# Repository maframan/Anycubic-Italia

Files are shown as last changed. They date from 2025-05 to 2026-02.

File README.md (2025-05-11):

# Anycubic-Italia
Repository ufficiale del gruppo telegram https://t.me/mfAnycubicIT

All'interno di questo repository sono presenti file e configurazioni che via via vengono prodotti all'interno del gruppo Telegram

Speciale ringraziamento a:
- Marco Robustini
- Alessio Fusi

che con i loro consigli ed il loro supporto ci permettono di avere stampe di qualità.

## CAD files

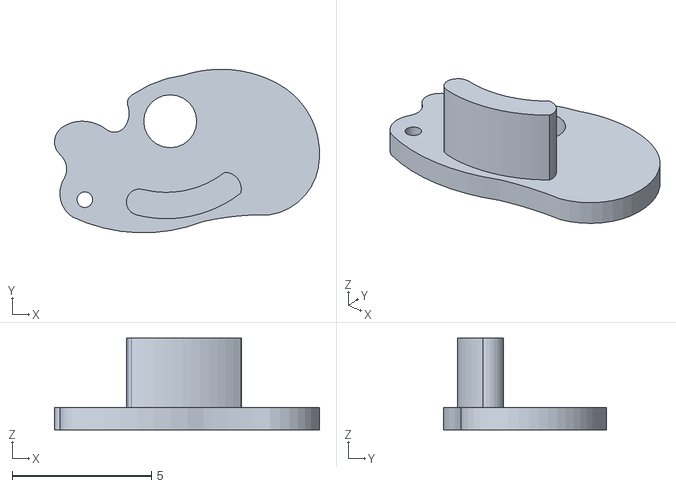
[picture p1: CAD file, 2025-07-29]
Kobra S1/STL/KOBRA_S1_FilamentSensorFlap.stl
9.51 x 5.86 x 3.30

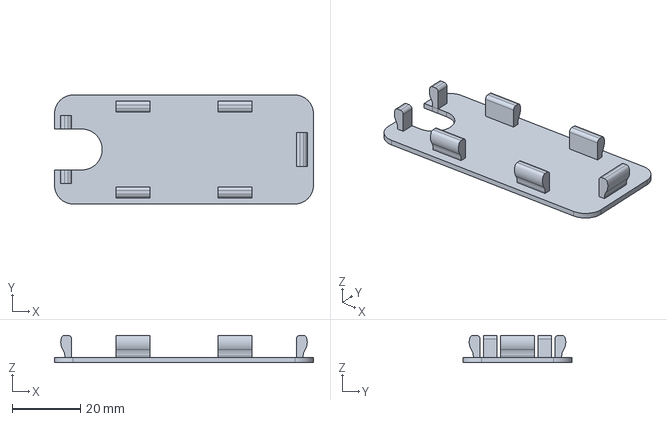
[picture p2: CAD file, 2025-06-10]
Kobra S1/STL/KS1_Cover_tappo piatto_alluminio_by_AlessioFusi.stp
76.0 x 32.0 x 8.00 mm

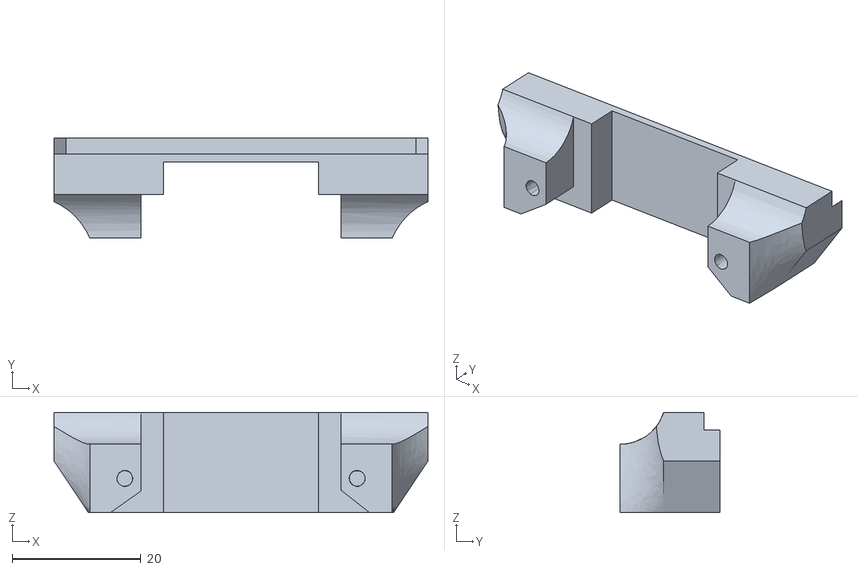
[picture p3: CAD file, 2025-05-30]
Kobra S1/STL/KS1_Plate_Aligner_for_original_plate_by_Danila.stl
58.0 x 15.5 x 15.5

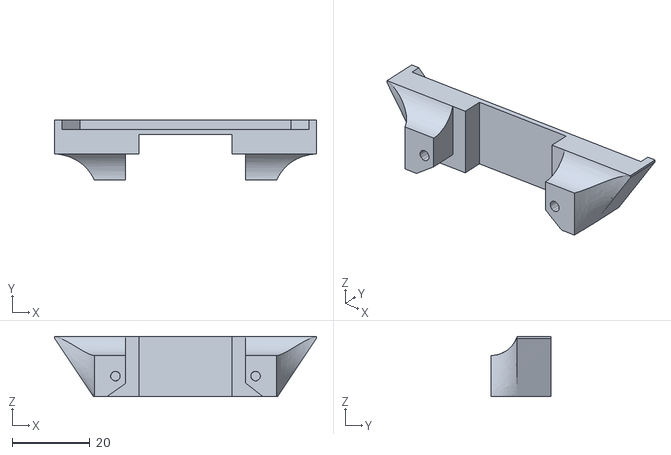
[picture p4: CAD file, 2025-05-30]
Kobra S1/STL/KS1_Plate_Aligner_for_aluminum_plate_by_AlessioFusi.stl
67.3 x 15.5 x 15.5

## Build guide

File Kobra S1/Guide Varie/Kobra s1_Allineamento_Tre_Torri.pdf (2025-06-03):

## Allineamento delle 3 Torri Z - Anycubic Kobra S1 (CoreXY)

Perché farlo?
Se una delle 3 torri Z non è sincronizzata (es. la destra è più alta o più bassa), il piatto non sarà parallelo all'asse XY, e l'autolivellamento LeviQ non potrà correggere adeguatamente. Questo può causare:
- Primo layer disastroso
- Compensazioni estreme nel mesh
- Movimenti strani in Z durante la stampa

Procedura corretta per allineare le torri Z

1. Spegni la stampante
Per evitare movimenti indesiderati e proteggere i driver.
2. Accedi alla cinghia sincronizzatrice Z
Metti la stampante su un fianco o sollevala con cautela. Individua la cinghia che collega le 3 torri Z (si trova sotto la base). Troverai una molla di tensione fissata su un lato.
3. Sgancia la molla
Sgancia delicatamente la molla della cinghia -> così disaccoppi le torri Z, che diventano indipendenti tra loro. Ora puoi ruotare manualmente ogni vite Z senza muovere le altre.
4. Porta ogni torre in battuta (punto più alto)
Ruota manualmente ogni torre fino a portarla in battuta contro il fine corsa superiore. Puoi anche usare un righello o squadra per verificare che il piatto sia alla stessa altezza su tutti e tre i lati.
5. Riaggancia la molla della cinghia
Una volta che le 3 torri sono meccanicamente allineate (stessa altezza), riaggancia la molla della cinghia. Così tornano sincronizzate.
6. Accendi la stampante e fai l'Homing
Fai un Home All per verificare che il piatto salga correttamente e non sia inclinato. A questo punto puoi anche rifare il bed leveling automatico (LeviQ 2.0) per aggiornare la mesh.

Ogni quanto va fatto?
- Dopo una disconnessione della corrente durante la salita/discesa del piatto.
- Dopo una manutenzione sulle viti Z.
- Se noti il piatto visibilmente inclinato da spento o layer iniziali storti.

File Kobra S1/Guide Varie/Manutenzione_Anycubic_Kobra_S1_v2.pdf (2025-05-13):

# Guida alla Manutenzione Approfondita della Anycubic Kobra S1

Questa guida fornisce istruzioni dettagliate per mantenere in perfetta efficienza la tua stampante 3D Anycubic Kobra S1. Una corretta manutenzione previene guasti, migliora la qualità delle stampe e prolunga la durata dei componenti.

## 📅 Frequenza consigliata

Attività | Frequenza
Pulizia del piatto | Ad ogni stampa
Pulizia ugello e hotend | Ogni 10-15 stampe
Ingrassaggio assi | Ogni 1-2 mesi
Controllo cinghie | Ogni 1-2 mesi
Controllo viti e eccentrici | Ogni 1-2 mesi
Controllo cablaggi e ventole | Ogni 3 mesi
Aggiornamento firmware | Ogni mese (se disponibile)

## 🧽 Pulizia della superficie di stampa

Mantenere pulita la superficie di stampa è essenziale per garantire l'adesione del primo layer. Residui di colla, grasso o impronte digitali possono compromettere la qualità della stampa e causare distacchi. Pulire regolarmente con alcool isopropilico rimuove questi contaminanti. Il lavaggio con acqua e sapone è utile per rimuovere residui più ostinati. L'acetone non va usato sul rivestimento PEI poiché può danneggiarlo. Quindi ricapitolando:

- Usa alcool isopropilico (IPA) su un panno morbido dopo ogni stampa.
- In caso di accumuli, lavalo con acqua calda e sapone neutro.
- Non usare acetone sul rivestimento PEI.

## 🔥 Pulizia ugello e hotend

Con il tempo, l'ugello può ostruirsi a causa di residui carbonizzati o detriti nel filamento. Una buona estrusione è cruciale per evitare sottoestrusione, layer mancanti o stampe fallite. Tecniche come il cold pull aiutano a rimuovere impurità interne senza smontare il blocco hotend. La sostituzione periodica dell’ugello è consigliata, soprattutto se si usano filamenti abrasivi (es. PLA con fibre di carbonio). Riassumendo:

- Verifica il flusso tramite la funzione di estrusione.
- Usa la tecnica del cold pull se l'ugello è ostruito.
- Pulisci l'hotend a caldo con un ago o spazzolino in ottone.
- Sostituisci l'ugello ogni 2-3 mesi (più spesso con materiali abrasivi).

## 🛢 Ingrassaggio guide lineari e assi

La lubrificazione riduce l'attrito tra parti mobili, evitando usura prematura, rumori e vibrazioni. Guide e barre non lubrificate causano movimenti discontinui e layer visibilmente irregolari. Un grasso al litio bianco o PTFE è ideale perché non attrae polvere e ha buona stabilità termica. È importante rimuovere il vecchio grasso prima di applicarne di nuovo per evitare grumi o impasti abrasivi. Riassumendo:

- Usa WD-40 Specialist al litio, grasso al PTFE o silicone.
- Pulisci le barre con alcool.
- Applica una piccola quantità di grasso e muovi gli assi.
- Rimuovi l'eccesso con un panno.

## 🔩 Controllo viti, eccentrici e cinghie

Durante l'uso, vibrazioni e spostamenti possono allentare viti e bulloni. Viti lente causano instabilità, vibrazioni e disallineamenti. Le ruote eccentriche vanno regolate per garantire scorrimento fluido ma senza gioco, riducendo il rischio di layer shift. Le cinghie devono essere ben tensionate per mantenere la precisione nei movimenti: troppo lasche causano imprecisioni, troppo tese possono usurare prematuramente cuscinetti e motori. Riassumendo:

- Verifica il serraggio di tutte le viti.
- Le ruote eccentriche devono girare senza gioco e senza eccessiva resistenza.
- Le cinghie X e Y devono essere ben tese ma non troppo strette.

## 🌬 Controllo ventole e cablaggi

Le ventole mantengono sotto controllo la temperatura di hotend, estrusore e scheda madre. Ventole bloccate o rumorose possono causare surriscaldamenti o malfunzionamenti. I cablaggi, soprattutto quelli in movimento (come sull’asse X), sono soggetti a piegature e usura. Un controllo visivo previene cortocircuiti o disconnessioni improvvise durante la stampa. Riassumendo:

- Controlla che tutte le ventole funzionino.
- Verifica l'integrità dei cavi, soprattutto quelli in movimento.

- Sostituisci cavi danneggiati o logori.

## 🔁 Livellamento del piatto

Anche con il sensore di autolivellamento, un piatto meccanicamente storto può causare variazioni nel primo layer. Un bed leveling corretto assicura che l’ugello sia sempre alla giusta distanza dal piatto, migliorando l’adesione e la precisione dimensionale. Rigenerare la mesh dopo modifiche o pulizie mantiene la calibrazione accurata. Riassumendo:

- Rigenera il bed mesh se noti qualcosa di anomalo nella qualità della stampa
- Ricontrolla il livellamento se cambi materiale o temperatura.
- Verifica allineamento delle torri

## 💾 Aggiornamento firmware

I firmware aggiornati spesso introducono ottimizzazioni, correzioni di bug o miglioramenti nelle funzioni del sensore di livellamento e dell’estrusione. Controllare periodicamente il sito Anycubic può aiutarti a mantenere la tua stampante al passo coi miglioramenti ufficiali.

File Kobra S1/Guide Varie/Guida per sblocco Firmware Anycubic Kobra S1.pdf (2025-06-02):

Guida per sblocco Firmware Anycubic Kobra S1

(link github Rinkhals: https://github.com/jbatonnet/Rinkhals).
NB: Tutte le indicazioni presenti nel documento sono a tuo rischio e pericolo e non mi ritengo in alcun modo responsabile delle problematiche/danni che ne potrebbero derivare.
Questa "mod" permette di sbloccare tutte le limitazioni di accesso al firmware originale di Klipper. rendendo la stampante individuabile nella rete, permettendo l'accesso tramite SSH e l'utilizzo di ORCA SLICER.
Tutte le caratteristiche del firmware originale Anycubic rimangono invariate.
Se stai seguendo questa guida ma hai gia fatto lo sblocco del firmware con una versione precedente del firmware aggiorna prima alla versione versione uQiciale (2.5.3.1).
Non si tratta di cambiare firmware alla stampante ma di modificare quello già installato, andando a sbloccare la possibilità di gestire tramite browser web KLIPPER (Mainsails o Fluidd)).
Questa guida è basata sulla repo ghithub del seguente link https://github.com/jbatonnet/Rinkhals
Tutte le nozioni qui riportate sono aggiornate all' ultima versione FW disponibile al momento della scrittura per tanto assicurarsi che le versioni software della kobra S1 sia la 2.5.3.1
Scaricate da questo LINK il pacchetto firmware: https://github.com/jbatonnet/Rinkhals/releases/download/20250531_01/update-ks1.swu (https://github.com/jbatonnet/Rinkhals/releases/download/20250531_01/update-ks1.swu)
Installazione del firmware:
1. Formatta una penna USB come FAT32 non troppo grossa 8 o 16gb sono piu che suQicenti
2. Crea una cartella denominata “aGVscF9zb3Nf” (attenzione a maiuscole e minuscole
3. Copia il file update-ks1.swu nella directory “aGVscF9zb3Nf”
4. Rinomina il file update-ks1.swu in update.swu
5. Estrai la chiavetta dal pc in modo sicuro
6. Collega la penna USB alla stampante
7. Dovresti sentire un segnale acustico, il che significa che la stampante ha rilevato il file di aggiornamento

8. Dopo circa 20 secondi (il tempo necessario alla stampante per preparare l'aggiornamento), vedrai una barra di avanzamento sullo schermo sulla destra
9. Se la barra di avanzamento diventa verde e senti 2 segnali acustici, la stampante si riavvia e la mod è pronta
10. Se la barra di avanzamento diventa rossa e senti 3 segnali acustici, l'installazione non è riuscita ma tutto dovrebbe comunque funzionare normalmente. Troverai maggiori informazioni nel file aGVscF9zb3Nf/install.log sulla penna USB del perché non sia stato possibile eseguire l’operazione.
11. Se tutto è andato come previsto, dovresti riuscire ad accedere alla web interface Fluidd della stampante raggiungibile alla seguente indirizzo: http://<ip_tua_stampante>:4408
Dato che la stampante non ha la possibilità di avere un indirizzo IP statico ma lavora solo in DHCP, tutte le volte che si spenge e riaccende potrebbe avere un indirizzo IP diverso. Vi consiglio di creare una regola nel vostro Router dove tiene in esclusiva un indirizzo IP da voi scelto assegnato al MAC della stampante cosi che ogni volta avrà il solito. non posso dirvi come fare perchè la procedura è diversa per ogni tipo di router.
NB: Se vuoi continuare a visualizzare la webcam tramite l’applicazione Anycubic segui la seguente guida: https://github.com/maframan/Anycubic-Italia/blob/main/Kobra%20S1/Guide%20Varie/Guida_Disattivazione_RinkHals_Stream er.mp4

Ripristino del firmware originale con la conseguente rimozione del firmware Rinkhals:

Nel caso per qualunque motivo ci fossero dei problemi o si vuole tornare al FW originale senza apertura di Klipper seguire questi passi.

1. Scaricare il seguente file: https://github.com/jbatonnet/Rinkhals/releases/download/20250531_01/install er-ks1.swu
2. Formatta una penna USB come FAT32 non troppo grossa 8 o 16gb sono piu che suQicenti
3. Crea una cartella denominata “aGVscF9zb3Nf” (attenzione a maiuscole e minuscole)
4. Copia il file installer-ks1.swu nella directory “aGVscF9zb3Nf
5. Rinomina il file installer-ks1.swu inupdate.swu
6. Estrai la chiavetta dal pc in modo sicuro
7. Collega la penna USB alla stampante

8. Dovresti sentire un segnale acustico, il che significa che la stampante ha rilevato il file di aggiornamento
9. Dopo circa 20 secondi (il tempo necessario alla stampante per preparare l'aggiornamento), la stampante si blocca ed avvierà l’installer
10.Avviato l’installer, cliccare su continue
11. Poi su Tools
12. Ed infine su Uninstall Rinkhals
13.Al termine la stampante si riavvia con una barra di caricamento in basso 14.Dopo il riavvio la stampante è pronta con il firmware originale installato

Questa guida è stata realizzata dal post facebook di Alessio Fusi che ringrazio personalmente per il preziosissimo contributo che da a noi possessori della stampante Anycubic Kobra S1.

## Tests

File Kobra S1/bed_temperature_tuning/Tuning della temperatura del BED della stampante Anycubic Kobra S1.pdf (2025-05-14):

Tuning della temperatura del BED della stampante Anycubic Kobra S1

Premessa: la procedura seguente è applicabile solo per coloro che hanno modificato il firmware con l’immagine Rinkhals (link github: https://github.com/jbatonnet/Rinkhals). NB: Tutte le indicazioni presenti nel documento sono a tuo rischio e pericolo e non mi ritengo in alcun modo responsabile delle problematiche/danni che ne potrebbero derivare.
La temperatura del bed nel riscaldamento tende ad eccedere il target richiesto, ad esempio in alcune stampe setto il bed a 70 gradi e me lo trovo a 75 nel primo riscaldamento, e la stampa prima di partire aspetta che si abbassi a 70 mettendoci un'infinità. Questo perché i pid dell'heater bed settati da Anycubic sono assolutamente sbagliati.
Passiamo alla procedura di configurazione:
1. Accedere alla web interface della stampante raggiungibile alla seguente indirizzo: http://<ip_tua_stampante>:4408
2. Andare nella dashboard e posizionarsi nella sezione Terminale

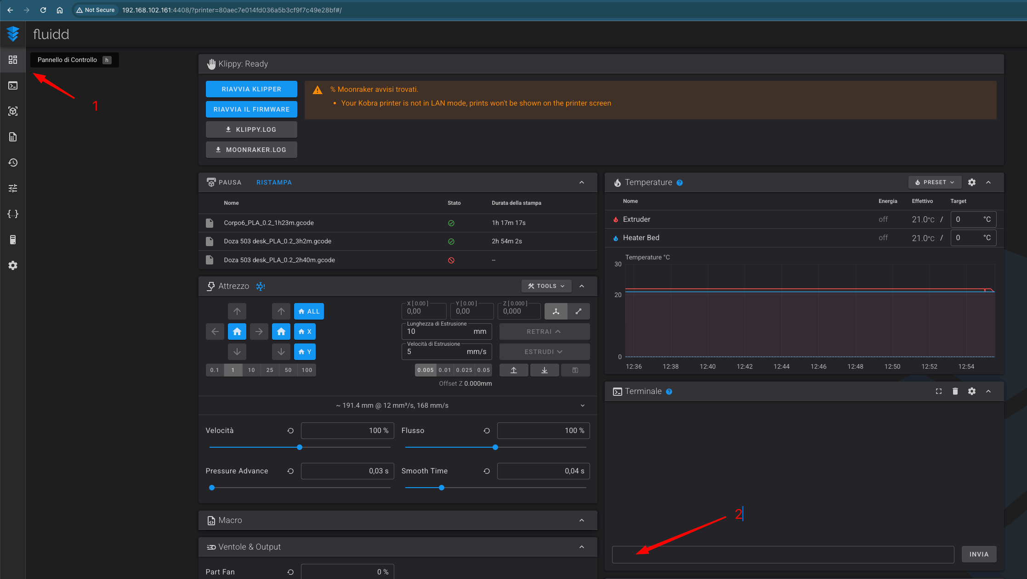
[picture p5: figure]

3. Lanciate il comando PID_CALIBRATE HEATER=heater_bed TARGET=70
4. Attendere che venga fatta la calibrazione del PID della temperatura
5. Finita la procedura di calibrazione prendere nota dei valori in output ed in particolare dei valori di pid_Kp, pid_Ki e pid_Kd
6. I tre valori andranno inseriti manualmente nel printer.custom.cfg come l’esempio seguente:
[heater_bed]

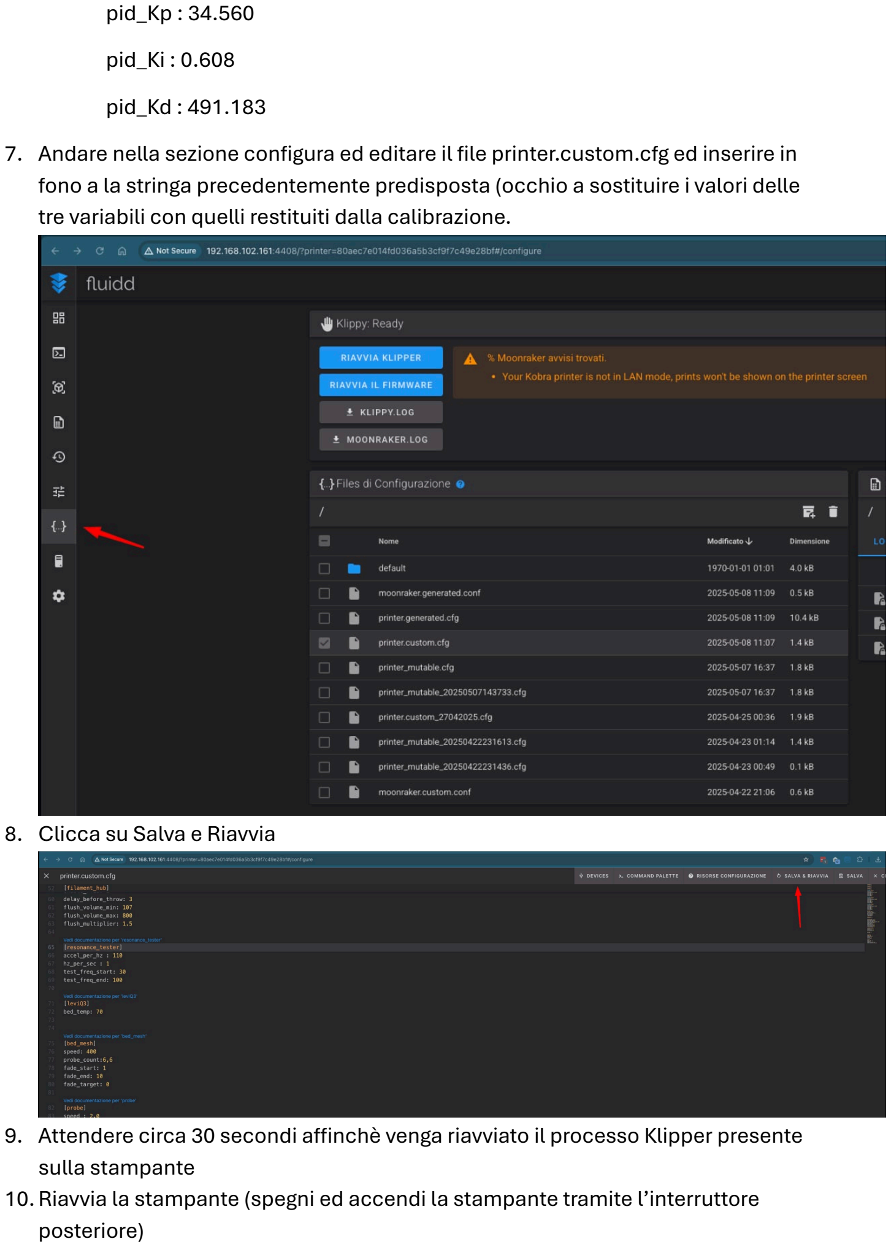
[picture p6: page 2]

pid_Kp : 34.560
pid_Ki : 0.608
pid_Kd : 491.183
7. Andare nella sezione configura ed editare il file printer.custom.cfg ed inserire in fono a la stringa precedentemente predisposta (occhio a sostituire i valori delle tre variabili con quelli restituiti dalla calibrazione.
8. Clicca su Salva e Riavvia
9. Attendere circa 30 secondi afinchè venga riavviato il processo Klipper presente sulla stampante
10.Riavvia la stampante (spegni ed accendi la stampante tramite l’interruttore posteriore)

Questa guida è stata realizzata dal post facebook di Marco Robustini che ringrazio personalmente!

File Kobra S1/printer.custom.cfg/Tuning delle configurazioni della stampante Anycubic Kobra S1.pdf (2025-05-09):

Tuning delle configurazioni della stampante Anycubic Kobra S1

Premessa: la procedura seguente è applicabile solo per coloro che hanno modificato il firmware con l’immagine Rinkhals (link github: https://github.com/jbatonnet/Rinkhals). NB: Tutte le indicazioni presenti nel documento sono a tuo rischio e pericolo e non mi ritengo in alcun modo responsabile delle problematiche/danni che ne potrebbero derivare.
Passiamo alla procedura di configurazione:
1. Accedere alla web interface della stampante raggiungibile alla seguente indirizzo: http://<ip_tua_stampante>:4408
2. Andare nella sezione Configura contrassegnata dalle parentesi graffe aperta e chiusa

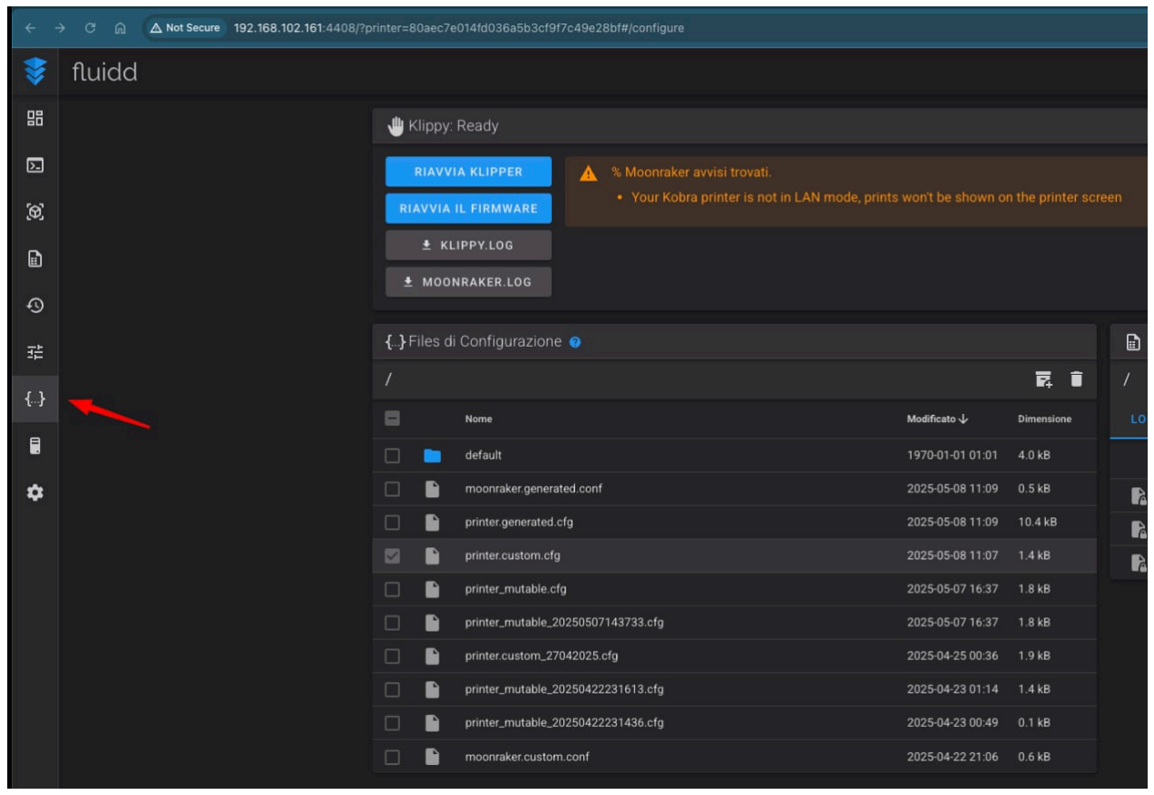
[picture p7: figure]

3. Selezionare il file printer.custom.cfg e incollare tutto il contenuto del file che ti ho inviato separatamente
4. Clicca su Salva e Riavvia

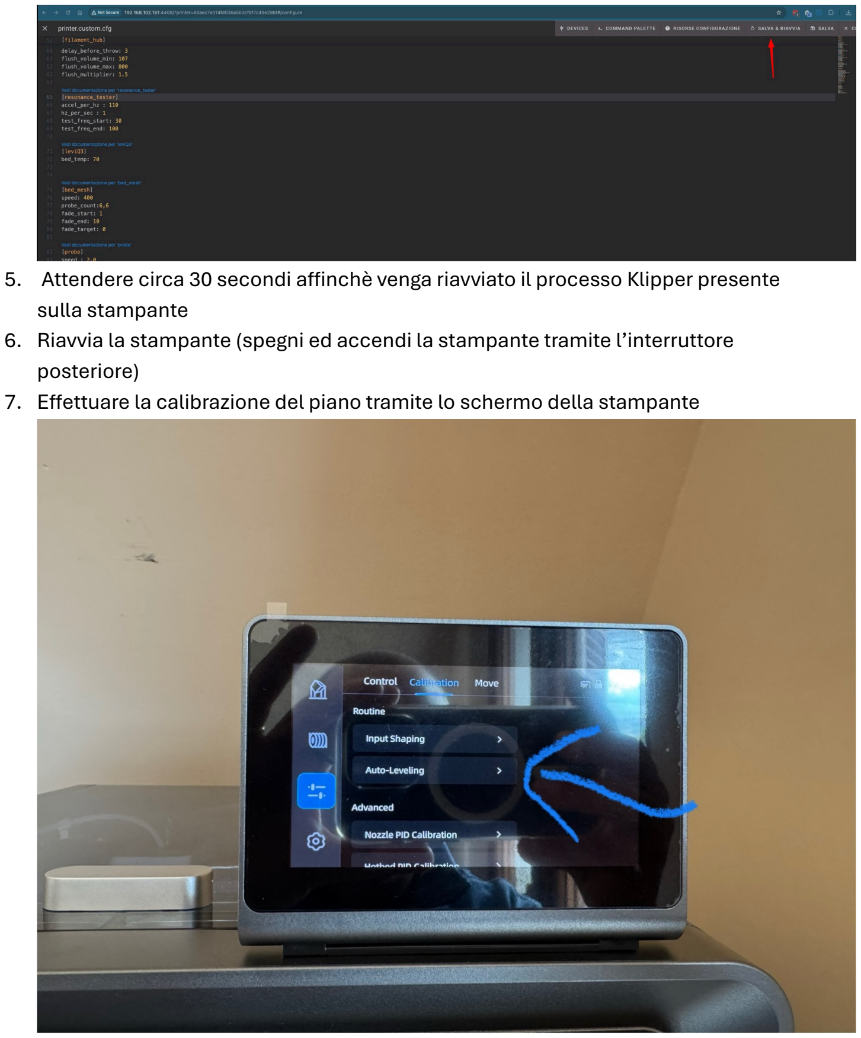
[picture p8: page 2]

5. Attendere circa 30 secondi aLinchè venga riavviato il processo Klipper presente sulla stampante
6. Riavvia la stampante (spegni ed accendi la stampante tramite l’interruttore posteriore)
7. ELettuare la calibrazione del piano tramite lo schermo della stampante

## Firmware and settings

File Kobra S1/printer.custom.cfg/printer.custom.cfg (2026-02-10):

# The content of this file will be merged with the main config file
# You can add new sections, properties, or override existing ones
# Check printer.generated.cfg to see the generated printer config used in GoKlipper

# You can override a section from the main config file by adding it here
# New properties will be merged and added, and existing ones will override the main config file
# [pause_resume]
# z_up: 11

# You can remove entire sections using a ! before the section name
# [!gcode_macro M486]

# You can also remove specific properties from a section using a ! before the property name
# [pause_resume]
# !z_up:

# Dare comando da terminale di Rinkhals: PID_CALIBRATE HEATER=heater_bed TARGET=80
[heater_bed] 
#pid_Kp : 40.930
#pid_Ki : 2.255
#pid_Kd : 185.719

# Dare comando da terminale di Rinkhals: PID_CALIBRATE HEATER=extruder TARGET=200
[extruder] 
#pid_Kp : 31.482
#pid_Ki : 7.773
#pid_Kd : 31.876

[stepper_x]
microsteps : 16

[stepper_y]
microsteps : 16

[stepper_z]
microsteps : 16
homing_speed: 8
homing_retract_dist:4
second_homing_speed:2

[tmc2209 stepper_x]
run_current : 1.3
!hold_current:
stealthchop_threshold: 99999
driver_SEMIN: 5
driver_SEUP: 1
driver_SEMAX: 5
driver_SEDN: 1
driver_SEIMIN: 0

[tmc2209 stepper_y]
run_current : 1.3
!hold_current:
stealthchop_threshold: 99999
driver_SEMIN: 5
driver_SEUP: 1
driver_SEMAX: 5
driver_SEDN: 1
driver_SEIMIN: 0

[tmc2209 stepper_z]
run_current : 1.5
!hold_current:
stealthchop_threshold: 99999
driver_SEMIN: 5
driver_SEUP: 1
driver_SEMAX: 5
driver_SEDN: 1
driver_SEIMIN: 0

[tmc2209 extruder]
run_current : 0.9
hold_current:0.5

[filament_hub]
default_unwind_speed:70
unwind_speed_old_ace:70
default_feed_speed: 80
unwind_length_after_triggered: 1250
feed_max_length: 2600
enable_feed_assist: 1
enable_rfid: 1
delay_before_throw: 3
flush_volume_min: 107
flush_volume_max: 800
flush_multiplier: 1.5

[printer]
max_accel:10000
!max_accel_to_decel:
square_corner_velocity:5.0
max_z_velocity:15
max_z_accel:250
!jump_speed_min :
!jump_speed_max :

[leviQ3]
bed_temp: 80

[bed_mesh]
speed: 200
mesh_pps:2,2
probe_count:6,6
algorithm: bicubic
bicubic_tension: 0.2
move_check_distance: 2.5
fade_start: 1
fade_end: 10
fade_target: 0

[probe]
speed : 2.0
final_speed : 2.0
samples: 3
samples_tolerance: 0.015
samples_tolerance_retries:10

[resonance_tester]
accel_per_hz : 110
hz_per_sec : 1
test_freq_start: 30
test_freq_end: 100

[gcode_arcs]
resolution: 0.1

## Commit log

2025-05-09 Inserimento configurazione Kobra S1
    [printer.custom.cfg]
2025-05-09 Modifica configurazione Kobra S1
    [printer.custom.cfg]
2025-05-09 Inserimento procedura calibrazione temperatura BED
2025-05-10 Inserimento video per la disabilitazione dello streaming RinkHals
2025-05-14 Update Guida per Tuning della temperatura del BED della stampante Anycubic Kobra S1
2025-05-18 Guida per installazione piatto di Alessio Fusi
2025-05-30 STL per supporto piatto Bambulab per piatto in alluminio di Alessio Fusi
    [Plate Aligner_v2.stl]
2025-05-30 STL modificato per piatto originale KS1
    STL per supporto piatto Bambulab per piano originale KS1
    [KS1_Plate Aligner_for_original_plate.stl]
2025-05-30 STL modificato per piatto originale KS1
    [KS1_Plate_Aligner_for_original_plate.stl]
2025-06-02 Aggiornamento guida per installazione Rinkhals con la versione del firmware della Kobra S1 2.5.3.1
2025-06-04 Video per diagnosticare problema di errata sensibilità del sensore di livellamento della Kobra S1
2025-06-10 Cover tappo piatto alluminio by AlessioFusi
    [KS1_Cover_tappo piatto_alluminio_by_AlessioFusi.stp]
2025-07-12 Update printer.custom.cfg Introduzione sezione finale dei pid calibrate
    [printer.custom.cfg]
2026-02-10 Update printer.custom.cfg with new settings
    Updated with the enhancement contributed by GermyPan!
    [printer.custom.cfg]
